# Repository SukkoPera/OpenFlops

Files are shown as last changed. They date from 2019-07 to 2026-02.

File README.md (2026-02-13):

# OpenFlops
OpenFlops is an Open Hardware Floppy Disk Drive emulator/simulator.

Board

### Summary
From [Wikipedia](https://en.wikipedia.org/wiki/Floppy_disk_hardware_emulator):
> Older models of computers, electronic keyboards and industrial automation often used floppy disk drives for data transfer. Older equipment may be difficult to replace or upgrade because of cost, requirement for continuous availability or unavailable upgrades. Proper operation may require operating system, software and data to be read and written from and to floppies, forcing users to maintain floppy drives on supporting systems.

> Floppy disks and floppy drives are gradually going out of production, and replacement of malfunctioning drives, and the systems hosting them, is becoming increasingly difficult. Floppy disks themselves are fragile, or may need to be replaced often. An alternative is to use a floppy disk hardware emulator, a device which appears to be a standard floppy drive to the old equipment by interfacing directly to the floppy disk controller, while storing data in another medium such as a USB thumb drive, Secure Digital card, or a shared drive on a computer network. Emulators can also be used as a higher-performance replacement for mechanical floppy disk drives. 

OpenFlops is an Open Hardware implementation of such an emulator, inspired from the ubiquitous Gotek hardware. It is designed to run the [FlashFloppy](https://github.com/keirf/FlashFloppy) firmware, which gives it several improvements over the original Gotek:
- Can be installed on [many different platforms](https://github.com/keirf/FlashFloppy/wiki/Host-Platforms)
- Directly supports a [wide range of image formats](https://github.com/keirf/FlashFloppy/wiki/Image-Formats)
- [Flexible track layout](https://github.com/keirf/FlashFloppy/wiki/Track-Layouts) for Raw Sector Images
- [Extremely configurable](https://github.com/keirf/FlashFloppy/wiki/FF.CFG-Configuration-File)
- Supports [AutoSwap](https://github.com/keirf/FF_AutoSwap) for games with a large number of disks
- Easily accessible pin headers for connection of a [i2c display](https://github.com/keirf/FlashFloppy/wiki/Hardware-Mods#lcd-display) (either OLED or LCD), [rotary encoder](https://github.com/keirf/FlashFloppy/wiki/Hardware-Mods#rotary-encoder) (including power)
- Built-in amplified speaker, or easily-accessible pin header for an external one
- USB connector can either be soldered on the board or connected to a pin header
- Connected Motor signal
- Emulates two drives at the same time (Not yet supported by the firmware, but [it will come](https://github.com/keirf/FlashFloppy/wiki/Donations))
- Has additional 3.3V, 5V and GND power pins
- And hey, it's Open Hardware!

All of this comes in the same form factor (and mounting holes) as the board installed in the original Gotek, hence it can be easily installed in any shell or enclosure designed for it.

### Assembly and Installation
Solder all components to the board. I suggest starting with the main microcontroller (U3), as it uses an LQFP package which is tricky to solder: the recommended technique is drag soldering, there are many videos about that on YouTube, so please look there for advice. I recommend soldering the bare minimum components needed for programming and then trying to flash it right away. This way you will be able to fix your soldering without too many components getting in the way, if needed. You will need a USB/TTL Serial converter for this: one with 3.3V I/O level is recommended, but a 5V one can be used, too (most pins on STM32 microcontrollers are 5V-tolerant, so don't worry, it's not a bad hack!). You shouldn't pay more than 1-2€ for it in any case, anyway. So, when you are ready:

- Solder U3, Y1, C3 and C5, then the programming header (the top one with power, BOOT0, TX, RX, etc.)
- Check for shorts on the 3.3V power lines, you can easily do this on the pads for C6-C10
- If your USB/Serial adapter has a 3.3V output, connect it to 3.3V on the power header, then connect ground, RX and TX
- If no 3.3V output is available, solder U4 and power the board through the 5V pin on the power header

Now you should be able to [program the STM32 microcontroller](https://github.com/keirf/FlashFloppy/wiki/Firmware-Programming). If you have difficultes you can try adding R10 (and C4) and maybe a few of C6-C10, but most likely the problem will be with the solder joints on U3, as soldering this kind of package manually is never easy, so please get a lens (or even better, a microscope) and double-check your job.

The serial adapter is only necessary for the first flashing. Subsequent updates [can be done easily via USB](https://github.com/keirf/FlashFloppy/wiki/Firmware-Update).

Note that most components are necessary, but there are a few you can skip if you are feeling lazy:
- If you are not interested in the head movement sound, you can skip the following components: SPK1, D2, R5, R6, Q7.
- If your LCD/OLED display already has pull-up resistors for the SDA/SCK lines (most do), you can skip R3 and R4.

### Configuration
Please refer to the FlashFloppy wiki for the [initial setup](https://github.com/keirf/FlashFloppy/wiki/Initial-Setup) and an overview of the [available configuration options](https://github.com/keirf/FlashFloppy/wiki/FF.CFG-Configuration-File).

Some options that you will want to override the default values of, in order to take advantage of all the features OpenFlops provides, are the following:
- `motor-delay`
- `rotary`
- `display-type`

### Releases
If you want to get this board produced, you are recommended to get [the latest release](https://github.com/SukkoPera/OpenFlops/releases) rather than the current git version, as the latter might be under development and is not guaranteed to be working.

Every release is accompanied by its Bill Of Materials (BOM) file and any relevant notes about it, which you are recommended to read carefully.

### License
The OpenFlops documentation, including the design itself, is copyright &copy; SukkoPera 2019-2020.

OpenFlops is Open Hardware licensed under the [CERN OHL v. 1.2](http://ohwr.org/cernohl).

You may redistribute and modify this documentation under the terms of the CERN OHL v.1.2. This documentation is distributed *as is* and WITHOUT ANY EXPRESS OR IMPLIED WARRANTIES whatsoever with respect to its functionality, operability or use, including, without limitation, any implied warranties OF MERCHANTABILITY, SATISFACTORY QUALITY, FITNESS FOR A PARTICULAR PURPOSE or infringement. We expressly disclaim any liability whatsoever for any direct, indirect, consequential, incidental or special damages, including, without limitation, lost revenues, lost profits, losses resulting from business interruption or loss of data, regardless of the form of action or legal theory under which the liability may be asserted, even if advised of the possibility or likelihood of such damages.

A copy of the full license is included in file [LICENSE.pdf](LICENSE.pdf), please refer to it for applicable conditions. In order to properly deal with its terms, please see file [LICENSE_HOWTO.pdf](LICENSE_HOWTO.pdf).

The contact points for information about manufactured Products (see section 4.2) are listed in file [PRODUCT.md](PRODUCT.md).

Any modifications made by Licensees (see section 3.4.b) shall be recorded in file [CHANGES.md](CHANGES.md).

The Documentation Location of the original project is https://github.com/SukkoPera/OpenFlops/.

### Support the Project
Since the project is open you are free to get the PCBs made by your preferred manufacturer, however in case you want to support the development, you can order them from PCBWay through this link:

PCB from PCBWay (https://www.pcbway.com/project/shareproject/OpenFlops_V1.html)

You get my gratitude and cheap, professionally-made and good quality PCBs, I get some credit that will help with this and [other projects](https://www.pcbway.com/project/member/shareproject/?bmbid=41100). You won't even have to worry about the various PCB options, it's all pre-configured for you!

Also, if you still have to register to that site, [you can use this link](https://www.pcbway.com/setinvite.aspx?inviteid=41100) to get some bonus initial credit (and yield me some more).

Again, if you want to use another manufacturer, feel free to, don't feel obligated :). But then you can buy me a coffee if you want:



### Thanks
- H.M for publishing the [original Gotek schematics](doc/gotek_usb-fde_block-diagram.jpg)
- [keirf](https://github.com/keirf) for FlashFloppy
- Brian Allan for suggesting some improvements for the Speaker circuit
- Ray Bellis for suggesting adding pin headers for the USB port and speaker
- Mario Babeu for suggesting to line up the orientation of LD1 and LD2
- Patrick Kerkhof for sending me a lot of original Gotek housing for dimensional testing

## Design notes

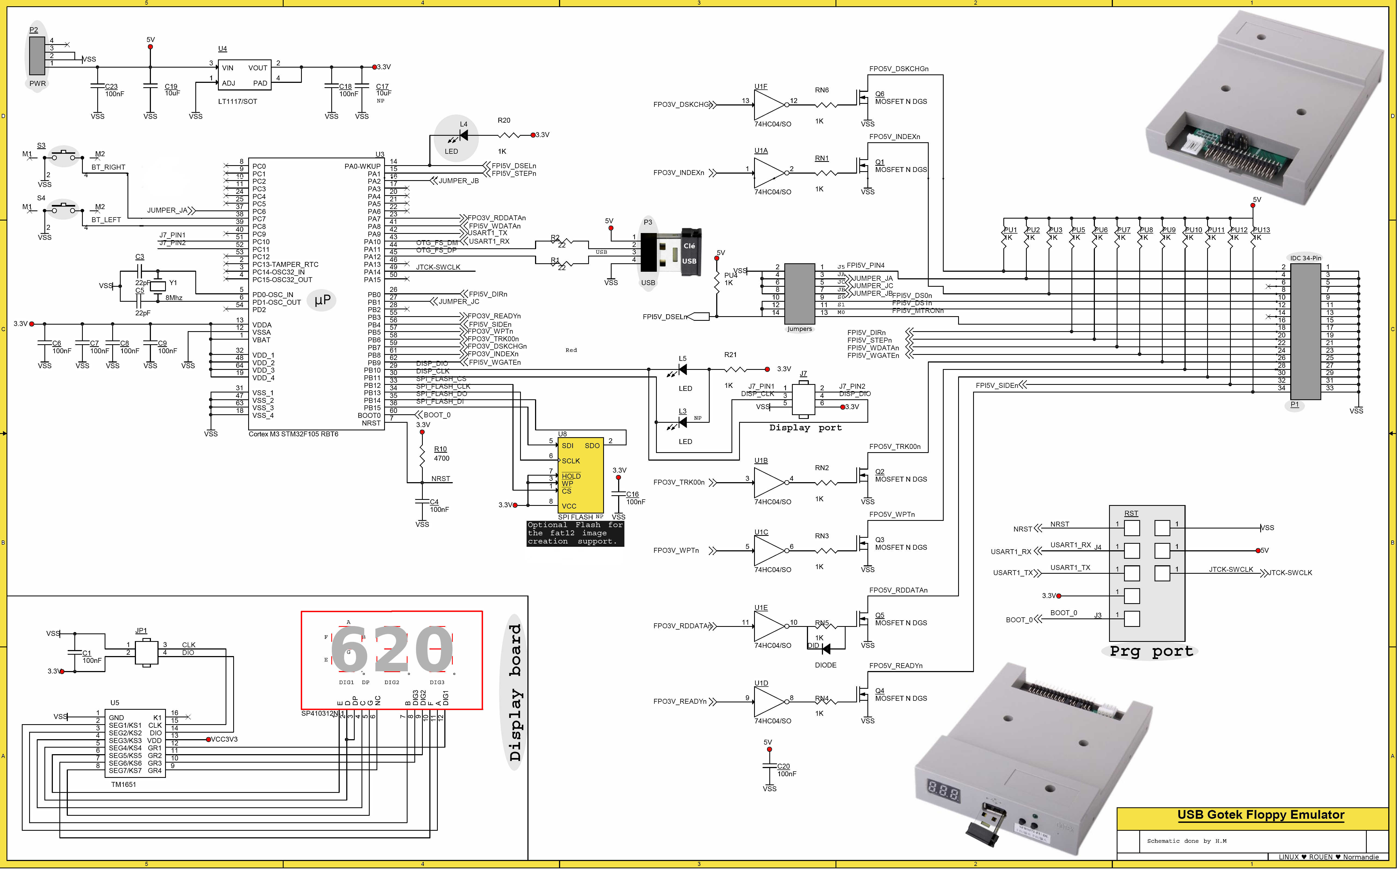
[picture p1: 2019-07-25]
doc/gotek_usb-fde_block-diagram.jpg

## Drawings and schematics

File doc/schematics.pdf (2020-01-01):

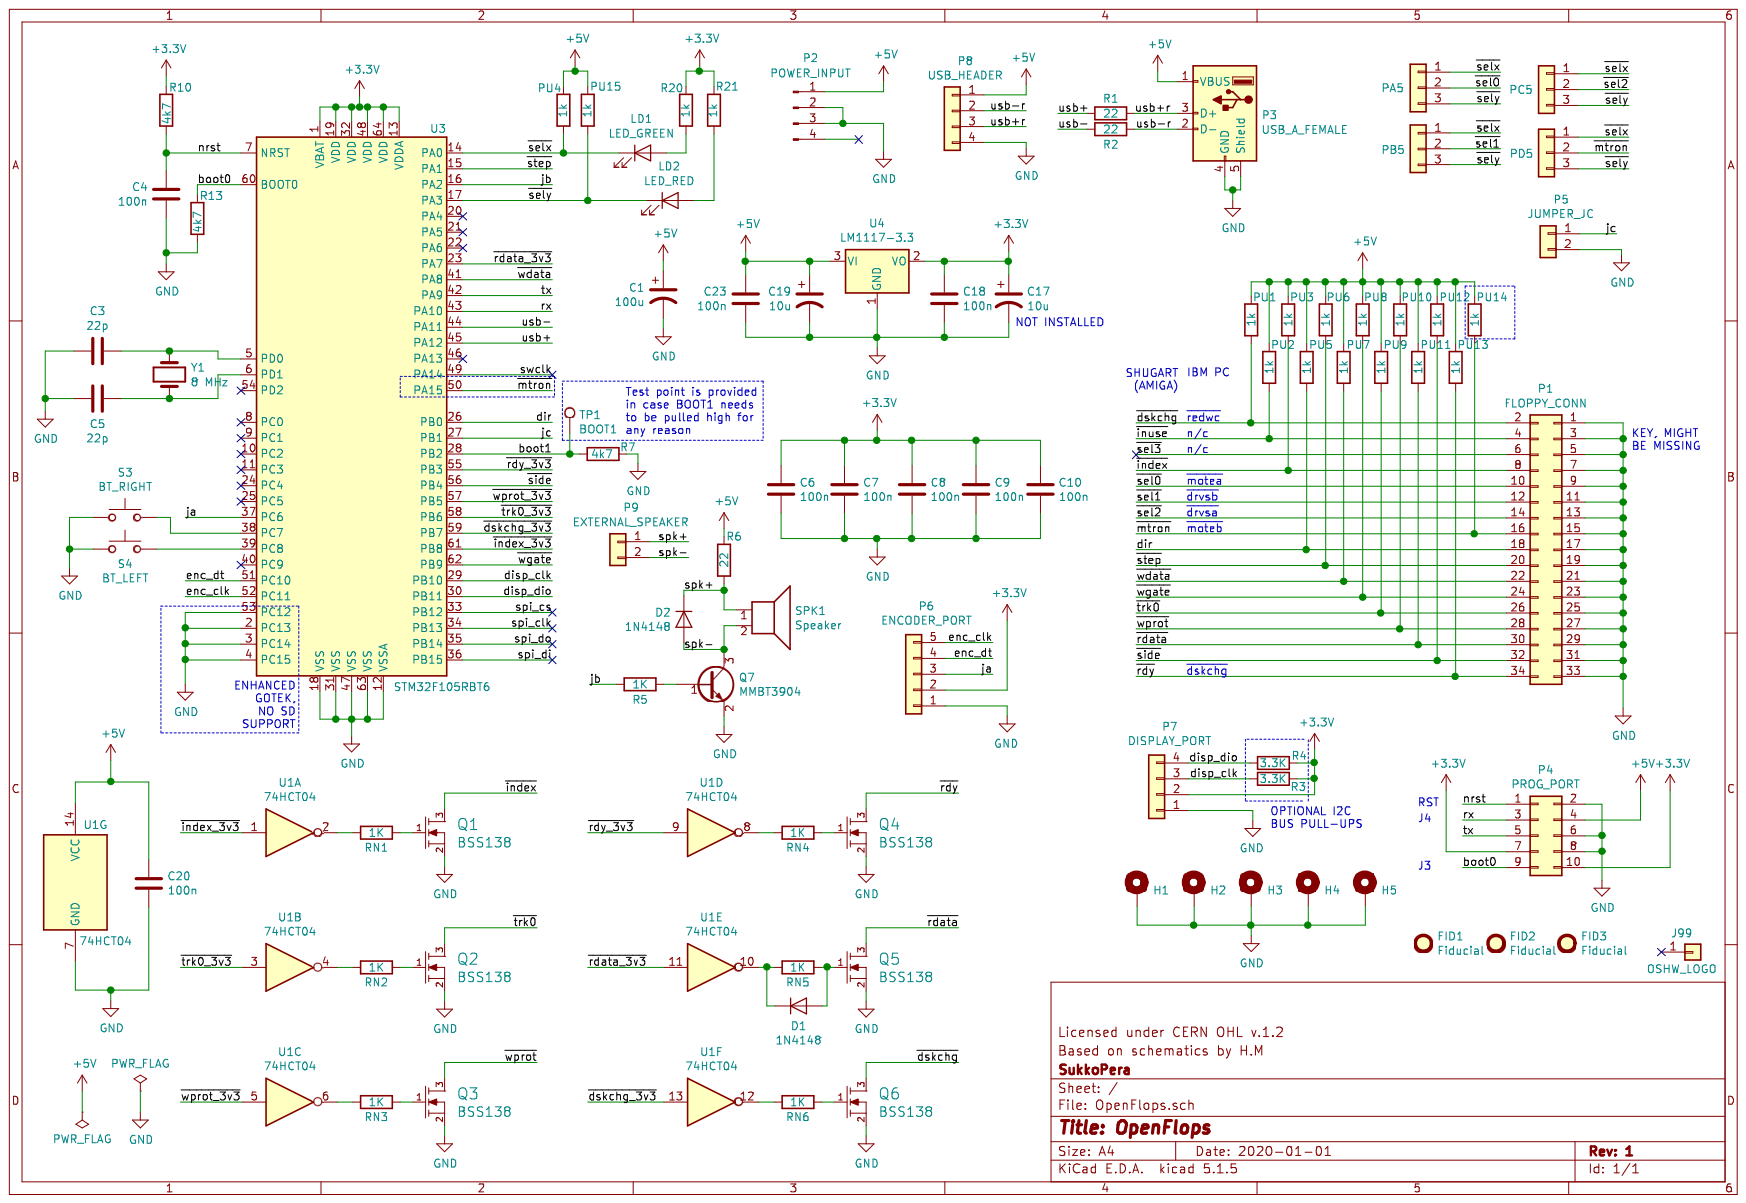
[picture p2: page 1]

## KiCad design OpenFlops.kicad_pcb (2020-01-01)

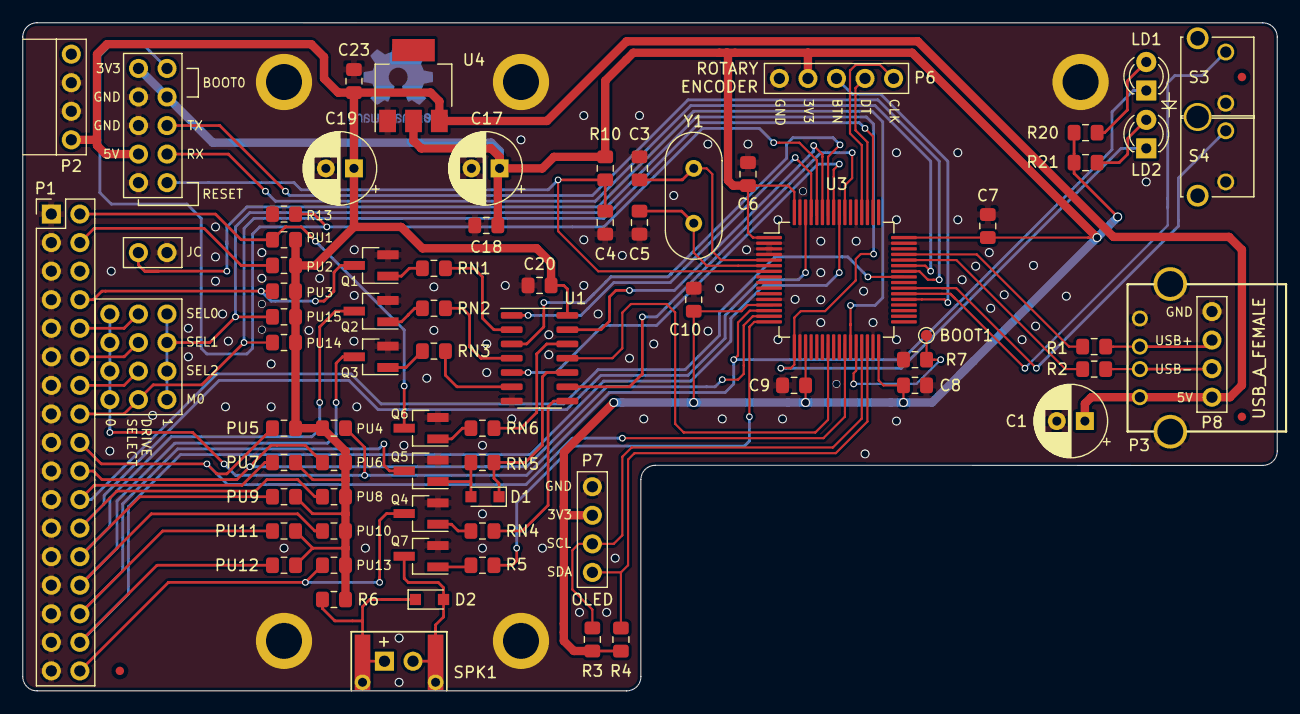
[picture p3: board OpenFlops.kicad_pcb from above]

Board: 2 copper layers, 111.6 x 59.4 mm, 87 parts (1 on the bottom side), 64 nets.

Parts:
C1: 100u; CP_Radial_D6.3mm_P2.50mm
C3, C5: 22p; C_0805_2012Metric_Pad1.15x1.40mm_HandSolder
C4, C6, C7, C8, C9, C10, C18, C20, C23: 100n; C_0805_2012Metric_Pad1.15x1.40mm_HandSolder
C17, C19: 10u; CP_Radial_D6.3mm_P2.50mm
D1, D2: 1N4148; D_SOD-323_HandSoldering
FID1, FID2, FID3: Fiducial; Fiducial_0.75mm_Mask1.5mm
H1, H2, H3, H4, H5: MountingHole_Pad; MountingHole_M3_Pad
J99: OSHW_LOGO; OSHW-Logo2_9.8x8mm_Copper
LD1: LED_GREEN; LED_D3.0mm
LD2: LED_RED; LED_D3.0mm
P1: FLOPPY_CONN; PinHeader_2x17_P2.54mm_Vertical
P2: POWER_INPUT; PinHeader_1x04_P2.54mm_Vertical
P3: USB_A_FEMALE
P4: PROG_PORT; PinHeader_2x05_P2.54mm_Vertical
P5: JUMPER_JC; PinHeader_1x02_P2.54mm_Vertical
P6: ENCODER_PORT; PinHeader_1x05_P2.54mm_Vertical
P7: DISPLAY_PORT; PinHeader_1x04_P2.54mm_Vertical
P8: USB_HEADER; PinHeader_1x04_P2.54mm_Vertical
P9: EXTERNAL_SPEAKER; PinHeader_1x02_P2.54mm_Mute
PA5: Conn_01x03; PinHeader_1x03_P2.54mm_Mute
PB5: Conn_01x03; PinHeader_1x03_P2.54mm_Mute
PC5: Conn_01x03; PinHeader_1x03_P2.54mm_Mute
PD5: Conn_01x03; PinHeader_1x03_P2.54mm_Mute
PU1, PU2, PU3, PU4, PU5, PU6, PU7, PU8, PU9, PU10, PU11, PU12, PU13, PU14, PU15: 1k; R_0805_2012Metric_Pad1.15x1.40mm_HandSolder
Q1, Q2, Q3, Q4, Q5, Q6: BSS138; SOT-23_Handsoldering
Q7: MMBT3904; SOT-23_Handsoldering
R1, R2, R6: 22; R_0805_2012Metric_Pad1.15x1.40mm_HandSolder
R3, R4: 3.3K; R_0805_2012Metric_Pad1.15x1.40mm_HandSolder
R5: 1K; R_0805_2012Metric_Pad1.15x1.40mm_HandSolder
R7, R10, R13: 4k7; R_0805_2012Metric_Pad1.15x1.40mm_HandSolder
R20, R21: 1k; R_0805_2012Metric_Pad1.15x1.40mm_HandSolder
RN1, RN2, RN3, RN4, RN5, RN6: 1K; R_0805_2012Metric_Pad1.15x1.40mm_HandSolder
S3: BT_RIGHT; PUSH_BUTTON_RIGHT_ANGLE
S4: BT_LEFT; PUSH_BUTTON_RIGHT_ANGLE
SPK1: Speaker; Buzzer
TP1: BOOT1; TestPoint_Pad_D1.0mm
U1: 74HCT04; SOIC-14_3.9x8.7mm_P1.27mm
U3: STM32F105RBT6; LQFP-64_Handsoldering
U4: LM1117-3.3; SOT-223-3_TabPin2
Y1: 8 MHz; Crystal_HC49-U_Vertical

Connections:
+3V3: C6.1, C7.1, C8.1, C9.1, C10.1, C17.1, C18.1, P4.7, P4.10, P6.2, P7.2, R3.1, R4.1, R10.1, R20.2, R21.2, U3.1, U3.13, U3.19, U3.32, U3.48, U3.64, U4.2
+5V: C1.1, C19.1, C20.1, C23.1, P2.1, P3.1, P4.4, P8.1, PU1.1, PU2.1, PU3.1, PU4.2, PU5.1, PU6.1, PU7.1, PU8.1, PU9.1, PU10.1, PU11.1, PU12.1, PU13.1, PU14.1, PU15.2, R6.2, U1.14, U4.3
/boot0: P4.9, R13.1, U3.60
/boot1: R7.2, TP1.1, U3.28
/dir: P1.18, PU5.2, U3.26
/disp_clk: P7.3, R3.2, U3.29
/disp_dio: P7.4, R4.2, U3.30
/enc_clk: P6.5, U3.52
/enc_dt: P6.4, U3.51
/ja: P6.3, U3.37
/jb: R5.2, U3.16
/jc: P5.1, U3.27
/nrst: C4.1, P4.1, R10.2, U3.7
/rx: P4.3, U3.43
/spk+: D2.1, P9.1, R6.1, SPK1.1
/spk-: D2.2, P9.2, Q7.3, SPK1.2
/tx: P4.5, U3.42
/usb+: R1.2, U3.45
/usb+r: P3.3, P8.3, R1.1
/usb-: R2.2, U3.44
/usb-r: P3.2, P8.2, R2.1
/~dskchg: P1.2, PU1.2, Q6.3
/~dskchg_3v3: U1.13, U3.59
/~index: P1.8, PU3.2, Q1.3
/~index_3v3: U1.1, U3.61
/~inuse: P1.4, PU2.2
/~mtron: P1.16, PD5.2, PU14.2, U3.50
/~rdata: P1.30, PU11.2, Q5.3
/~rdata_3v3: U1.11, U3.23
/~rdy: P1.34, PU13.2, Q4.3
/~rdy_3v3: U1.9, U3.55
/~sel0: P1.10, PA5.2
/~sel1: P1.12, PB5.2
/~sel2: P1.14, PC5.2
/~selx: LD1.1, PA5.1, PB5.1, PC5.1, PD5.1, PU4.1, U3.14
/~sely: LD2.1, PA5.3, PB5.3, PC5.3, PD5.3, PU15.1, U3.17
/~side: P1.32, PU12.2, U3.56
/~step: P1.20, PU6.2, U3.15
/~trk0: P1.26, PU9.2, Q2.3
/~trk0_3v3: U1.3, U3.58
/~wdata: P1.22, PU7.2, U3.41
/~wgate: P1.24, PU8.2, U3.62
/~wprot: P1.28, PU10.2, Q3.3
/~wprot_3v3: U1.5, U3.57
GND: C1.2, C3.2, C4.2, C5.2, C6.2, C7.2, C8.2, C9.2, C10.2, C17.2, C18.2, C19.2, C20.2, C23.2, H1.1, H2.1, H3.1, H4.1, H5.1, P1.1, P1.3, P1.5, P1.7, P1.9, P1.11, P1.13, P1.15, P1.17, P1.19, P1.21, P1.23, P1.25, P1.27, P1.29, P1.31, P1.33, P2.2, P2.3, P3.4, P3.5, P4.2, P4.6, P4.8, P5.2, P6.1, P7.1, P8.4, Q1.2, Q2.2, Q3.2, Q4.2, Q5.2, Q6.2, Q7.2, R7.1, R13.2, S3.1, S4.1, U1.7, U3.2, U3.3, U3.4, U3.12, U3.18, U3.31, U3.47, U3.53, U3.63, U4.1
unnamed: C3.1, U3.5, Y1.1
unnamed: C5.1, U3.6, Y1.2
unnamed: D1.1, RN5.2, U1.10
unnamed: D1.2, Q5.1, RN5.1
unnamed: LD1.2, R20.1
unnamed: LD2.2, R21.1
unnamed: Q1.1, RN1.1
unnamed: Q2.1, RN2.1
unnamed: Q3.1, RN3.1
unnamed: Q4.1, RN4.1
unnamed: Q6.1, RN6.1
unnamed: Q7.1, R5.1
unnamed: RN1.2, U1.2
unnamed: RN2.2, U1.4
unnamed: RN3.2, U1.6
unnamed: RN4.2, U1.8
unnamed: RN6.2, U1.12
unnamed: S3.2, U3.38
unnamed: S4.2, U3.39

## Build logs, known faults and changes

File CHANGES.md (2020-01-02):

## CHANGES

Any modifications to the OpenFlops design and documentation made by any Licensee MUST be noted in this file, as per *section 3.4.b* of the [license](LICENSE.pdf).

### (Date) - (Author)
(Description)

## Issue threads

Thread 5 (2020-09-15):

Strange issue on openflops hardware with FlashFloppy

ixmeins, 2020-09-15:
I've built up several Openflops boards and flashed them with Flashfloppy 3.16 (and tried older versions). One out of 5 boards will successfully work with any Amstrad disk image files (DSK or HFE) whereas the others all return read errors from the OS when trying to use DSK files. I have compared the boards and can't see any differences. Waveforms on read, index etc all look very similar on the scope. These same "faulty" boards will work with HXC firmware. Has anyone else experienced this type of behaviour on the openflops hardware?

simulant-systems, 2020-09-16:
Hi I just wanted to reply here as I noticed on the FlashFloppy issues section that this has been fixed by doing a RESET holding both buttons :)

SukkoPera, 2020-09-16:
Thanks @simulant-systems. @ixmeins Can you please confirm?

SukkoPera, 2020-10-11:
I'm closing this even if we got no reply. I assume no more comments means everything's working fine.

Closed 2020-10-11.

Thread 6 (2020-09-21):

idea: internal solution together with floppy drive

uli42, 2020-09-21:
I would like to install the emulator internally without removing the built-in floppy drive and being able to switch between the two. I have found someone who has done that using a modified floppy cable and a hardware switch for Amiga 1200: https://www.ikod.se/amiga-1200-gotek

Now, my suggestion is add another (optional) connector to the PCB where you can connect the original internal floppy drive that was replaced by OpenFlops and add the switching logic to the pcb. The switch could then be done via FlashFloppy (which would have to be extended, of course).

Connection schematics: mainboard -> (original unmodified floppy cable) -> openflops -> (unmodifed floppy cable) -> floppy drive

For a perfect internal usage some external PCB with a single connector to OpenFlops for buttons/rotary, display and usb port would enable people to use that setup without any modification to their case.

SukkoPera, 2020-09-21:
I think it's a nice idea. Personally, I'm not interested in it, but if you want to go ahead and do it yourself, I'll happily accept a PR.

I'm also applying the "help wanted" label, just in case someone else wants to help.

uli42, 2020-09-22:
Unfortunately I have zero skills in stuff like that ;-(

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

SukkoPera, 2020-09-22:
I'll leave this ticket open then. Cross your fingers :).

uli42, 2020-09-29:
FWIW: I have come across a project which implements this idea with a gotek: https://www.forum64.de/index.php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 (in German)

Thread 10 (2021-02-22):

Please add Pin1 marker for U1 and U3

phako, 2021-02-22:
Not strictly necessary, but would improve convenience :)

SukkoPera, 2021-02-22:
The marker is already there. The silkscreen has a longer line on the pin 1 side. I agree it's pretty hard to see, but it's the way KiCad footprints are designed and I don't want to modify them just for this. Ask them to make their footprints clearer :).

phako, 2021-02-22:
Ohhh, right. Totally didn't get that, was looking for the dot :) Nevermind then

Closed 2021-02-22.

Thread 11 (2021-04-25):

Idea: add 26pin connector version

crazycusti, 2021-04-25:
hi!

this board would be awesome for my old 486 notebook :)

but it had an 26pin slim connector (like citizen w1d floppydrives)

i had no skills to change the gerberfiles. :(

SukkoPera, 2021-04-25:
This is a very good idea, but I'm not going to do it. Hopefully someone will help, tagging as *help wanted*.

cyberluke, 2022-01-28:
I would do it if I know how to learn to do it. Any ideas where to learn what kind of connector is required? For example PCD-4ND and PCD-5ND have floppy in some kind of boxed module and the connector outside is not a standard 26pin FPC. Then some use 1.0mm FPC, some use 0.5mm FPC. That would be still okay, you can find the pinout. But someone would need to recommend what software to use to modify the gerberfiles and where to get all these connectors from old 486 laptops (not just FPC).

SukkoPera, 2022-01-29:
You don't want to modify the Gerber files, LOL. This really says it all why people do not understand how much added value an open source project is, wrt those that are just "free gerbers", sigh.

What you want to do is use [KiCad](https://www.kicad.org) (this project currently uses KiCad 5) to update the schematics and the PCB and - only then - regenerate the gerbers for production.

[This](https://docs.kicad.org/6.0/en/getting_started_in_kicad/getting_started_in_kicad.html) happens to be a good KiCad Tutorial, it's an updated versione of the same one I used a few years ago to get started.

I can't help with the different connectors, unfortunately, never seen one of those drives.

bschwand, 2022-11-23:
you can buy an fpc 26 to 34 pin header for a few bucks on aliexpress

SukkoPera, 2022-11-23:
Sigh.

csulaguy, 2023-02-15:
After some googling, I ended up here for the same reason as the OP. Unfortunately, I also don't know the first thing about designing a circuit board. In regards to @bschwand , I'm sure you could do an adapter, but why? I think having a **native** 26 pin version makes more sense for those of us who use laptop-style drives. I know there are musical instruments and industrial control devices that also use the same laptop-style drives.

SukkoPera, 2023-02-15:
That's exactly the point of open source stuff: you can see how it's made and modify it to suit your needs, rather than being just a way to make a quick buck as seems to be the common understanding in the retrocomputing community.

It actually *thrives* when many people do so, so just pick the tutorial and do it, it's an excellent task for learning some basics that will surely turn out useful in the future.

mpictor, 2024-06-13:
This would be helpful to me as well. Can't promise anything but I will try to find time to do it.

I'm hoping it's possible to fit both footprints on the PCB so it can be used either way (depending on which is populated).

SukkoPera, 2024-06-14:
I think this has now been done: https://github.com/silvervest/OpenFlops-W1D.

Closed 2024-08-23.

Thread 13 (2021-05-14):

Is there a replacement for the U3?

dippaolo, 2021-05-14:
Is there a replacement for the U3?

Access to the STM32F105RBT6 microcontroller is difficult.

You can get it, but it's expensive :(

SukkoPera, 2021-05-14:
No, feel free to mod the design to use a different IC.

Bytedecode72, 2021-12-02:
i've got some GD32F105RBT6 coming instead of the STM32F105RBT6

SukkoPera, 2021-12-02:
If it works, can you please provide a link to where those can be bought?

ra1nb0w, 2022-03-05:
@Bytedecode72 any news with GD32F105RBT6? thank you

ra1nb0w, 2022-03-09:
seems that also `AT32F415RCT7` (from new GOTEK boards) is usable but not findable in the market

Bytedecode72, 2022-03-21:
> @Bytedecode72 any news with GD32F105RBT6? thank you

i got the  chips just need to order other components and assemble then get debug firmware on there to see if anything is tripping it up.

ra1nb0w, 2022-03-21:
Thank you @Bytedecode72 for the update. Report back when it will work (or not).

Bytedecode72, 2022-03-25:
> Thank you @Bytedecode72 for the update. Report back when it will work (or not).

i will do just waiting on the components now all sourc
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
e

ra1nb0w, 2022-03-25:
I bought an GD32F105RBT6 too. We will see ;-)

SzymonGk, 2022-10-22:
> > Thank you @Bytedecode72 for the update. Report back when it will work (or not).
>
> i will do just waiting on the components now all sourc 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 e

Hi, any update regarding GD32F105RBT6?

SzymonGk, 2023-01-22:
I do not think that GD32F105RBT6 is compatible substitution for STM32F105RBT6. I soldered IC to the board and programmed with hex flie provided for STM32F105RBT6 (FlashFloppy), unfortunately device does not work. I programmed it via two methods, first via Demonstrator Gui and second via StLink2 soldering two thin wires to pins 46(SWDIO) and 49(SWCLK). I tried also Giga Devices programming software but it crashes when hex file selected.

SukkoPera, 2023-01-22:
It should be compatible but it requires a dedicated firmware, I think. Please see the FlashFloppy project page.

jduraes, 2025-01-20:
> > Thank you [@Bytedecode72](https://github.com/Bytedecode72) for the update. Report back when it will work (or not).
>
> i will do just waiting on the components now all sourc 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 e

Would you be so kind to share your BOM file, unless one already exists somewhere? Saves typing it and avoiding mistakes. Thanks.

Bytedecode72, 2025-01-21:
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

[openflops_1-2_11 boardsbom.zip](https://github.com/user-attachments/files/18492082/openflops_1-2_11.boardsbom.zip)

i haven`t been able to do any assembly due to health issues and numb fingers, but i`ll attached the excel bom file

jduraes, 2025-01-21:
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

Thank you very much.

I know the numb hands feeling all too well myself, as I can only do about an hour or so of soldering. Hope you get well on that.

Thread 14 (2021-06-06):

First PCB assembly

dippaolo, 2021-06-06:
PCB ordered from PCBWAY from the link:
https://www.pcbway.com/project/shareproject/OpenFlops_V1.html

I got 1 piece of STM microcontroller.

I soldered by dragging the soldering iron over the legs.
I checked under the microscope.
I soldered Y1, C3, C5, BOOT0, TX, RX.
Programmed microprocessor - successful :)

In the next step I want to solder P7. Is it enough to see the inscription on OLED FlashFloppy?

SukkoPera, 2021-06-07:
I think so, you might also need R3 and R4 depending on your particular OLED screen.

Closed 2021-06-07.

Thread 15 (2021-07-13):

How to connect OpenFlops for IBM 3174?

blackbit42, 2021-07-13:
Hi

The FlashFloppy documentation has instructions to install a diode between two pins for operation in an IBM 3174 controller.
That documentation is focused on the original GoTek hardware.
Pin header layout and designations on the OpenFlops are different.
Can you please advise which pins on the OpenFlops are equivalent to [this](https://github.com/keirf/FlashFloppy/wiki/Host-Platforms#ibm-3174) so I can install that diode correctly.

SukkoPera, 2021-07-13:
I **think** it goes like this:

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

And put a jumper between 0 and SEL1.

**No guarantees!**

blackbit42, 2021-07-14:
Works like a charm. Thanks!

Closed 2021-07-14.

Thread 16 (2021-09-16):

Where is the BOM?

bjstigall, 2021-09-16:
I can't find the Bill of Materials.

SukkoPera, 2021-09-18:
Just open your eyes.

bjstigall, 2021-09-18:
Very professional, thanks.

Sent from Outlook<https://aka.ms/qtex0l> for iOS
________________________________
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

bjstigall, 2021-09-18:
Thanks for the help.

Sent from Outlook<https://aka.ms/qtex0l> for iOS
________________________________
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

Closed 2021-09-18.

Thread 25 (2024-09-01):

Cannot load file from USB

Vanles, 2024-09-01:
I soldered three boards. FlashFloppy works, the display turns on and shows the contents. When the Amiga starts, it tries to load from the USB, but nothing happens. Has anyone had this problem and knows which component I should look for?

Loading the company software via the USB also works. So it could have something to do with the connection on the floppy disk.

All three boards have the same problem.

Thanks
Marco

SukkoPera, 2024-09-02:
Did you put a jumper between SEL0 and 0? Also try putting/removing one on JC and/or configure FlashFloppy to Shugart mode explicitly from its settings file.

Vanles, 2024-09-02:
I found the problem. A dealer sent me a bad chip. Not the 74HCT04 but the 74HCT02. After replacing it, the drives work.

SukkoPera, 2024-09-02:
Well, that is certainly interesting! Glad you found the issue :).

Closed 2024-09-02.

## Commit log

2019-07-25 Fix PU3
    [OpenFlops.sch]
2019-07-25 Fix JB/JC
    [OpenFlops.sch]
2019-07-27 And we're done! This is a first rev of the PCB, done "by eye" as similarly as possible as one of my boards. There are quite a few improvements that we can make...
    [OpenFlops.kicad_pcb, OpenFlops.sch]
2019-07-27 Add mounting holes and several refinements
    [OpenFlops.kicad_pcb, OpenFlops.sch]
2019-07-27 Fix labels
    [OpenFlops.kicad_pcb]
2019-07-28 Improve power distribution
    [OpenFlops.kicad_pcb]
2019-07-28 Put power connectors on spare P4 pins
    [OpenFlops.kicad_pcb, OpenFlops.sch]
2019-07-28 Fix track width
    [OpenFlops.kicad_pcb]
2019-08-04 Make this an enhanced drive for FlashFloppy
    [OpenFlops.sch]
2019-08-04 Add current-limiting resistor on speaker
    [OpenFlops.sch]
2019-08-04 Add protection diode on speaker. Thanks Brian Allan
    [OpenFlops.sch]
2019-08-04 Update PCB
    [OpenFlops.kicad_pcb, OpenFlops.sch]
2019-08-04 Improve ground plane
    [OpenFlops.kicad_pcb]
2019-08-04 Add P6/P7 pin names
    [OpenFlops.kicad_pcb]
2019-08-04 74HC04 -> 74HCT04
    [OpenFlops.kicad_pcb, OpenFlops.sch]
2019-08-04 Some refinements
    [OpenFlops.kicad_pcb]
2019-08-14 Rework power tracks, depolarize OLED/encoder connectors
    [OpenFlops.kicad_pcb, OpenFlops.sch]
2019-08-14 Use SOT-23 footprints for MOSFETs
    [OpenFlops.kicad_pcb, OpenFlops.sch]
2019-08-18 Use SOD-323 footprint for diodes
    [OpenFlops.kicad_pcb, OpenFlops.sch]
2019-08-18 Minor silkscreen adjustments
    [OpenFlops.kicad_pcb]
2019-08-18 Use same orientation for LD1 and LD2 - Thanks Mario Babeu
    [OpenFlops.kicad_pcb]
2019-08-18 Fix LD2 silkscreen position and add LED install legend
    [OpenFlops.kicad_pcb]
2019-08-18 Better position LED legend
    [OpenFlops.kicad_pcb]
2019-08-18 Add header for USB and speaker signals - Thanks Ray Bellis
    [OpenFlops.kicad_pcb, OpenFlops.sch]
2019-08-21 Lotsa cosmetic fixes
    [OpenFlops.kicad_pcb, OpenFlops.sch]
2019-08-21 Make LQFP-64 footprint easier to handsolder
    [OpenFlops.kicad_pcb, OpenFlops.sch]
2019-08-21 Ready for V1!
    [OpenFlops.kicad_pcb, OpenFlops.sch]
2019-10-09 Fix #2
    [OpenFlops.kicad_pcb, OpenFlops.sch]
2019-10-09 Fix #3
    [OpenFlops.kicad_pcb]
2019-10-09 Fix #4
    [OpenFlops.kicad_pcb, OpenFlops.sch]
2019-10-09 Make R6 22R
    [OpenFlops.kicad_pcb, OpenFlops.sch]
2019-10-09 Fix dimension
    [OpenFlops.kicad_pcb]
2019-10-09 Some more ground stitching
    [OpenFlops.kicad_pcb]
2019-10-09 Add BOOT1 testpoint and lots of changes for auto P&P
    [OpenFlops.kicad_pcb, OpenFlops.sch]
2020-01-01 Final touches for V1final
    [OpenFlops.kicad_pcb, OpenFlops.sch]
2020-01-01 Fixes for BOM
    [OpenFlops.kicad_pcb, OpenFlops.sch]

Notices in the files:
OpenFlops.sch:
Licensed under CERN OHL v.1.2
